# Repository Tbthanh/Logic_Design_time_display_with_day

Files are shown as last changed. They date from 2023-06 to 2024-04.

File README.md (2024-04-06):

# Logic_Design_time_display_with_day<br>

**Team's member:**<br>
Đinh Quoc An<br>
Bui Manh Huy<br>
Nguyen The (Saxo Cat) Minh Quan<br>
Tran Ba Thanh<br>
Nguyen Minh Tuan<br>

**Project objective:**<br>
This project aim is to deepen our knowledge about logic design, ic 74xx series, CAD-SPICE sofware (proteus, altium),...

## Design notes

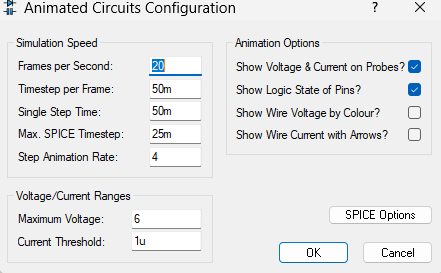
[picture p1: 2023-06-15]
Multimedia/Default_option_for_animation_Proteus.png

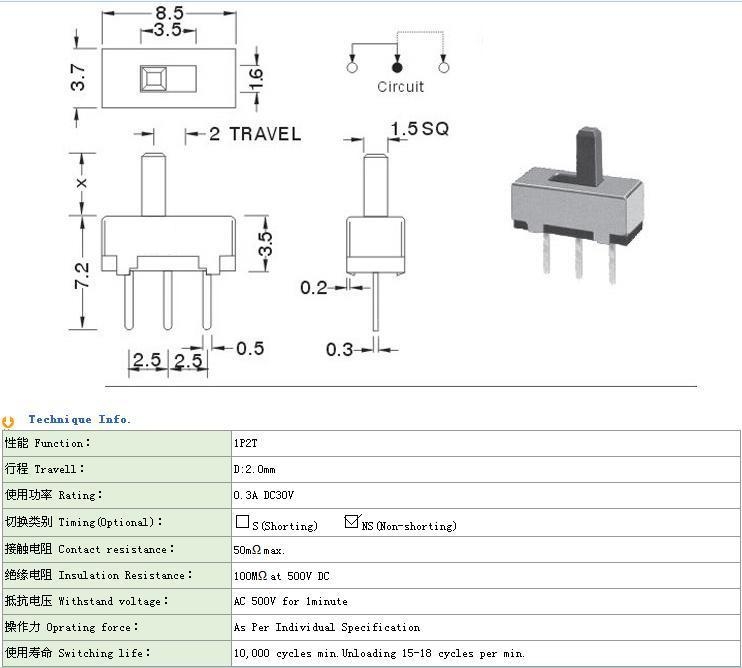
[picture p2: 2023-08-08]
Document/Switch/SS-12D002.jpg

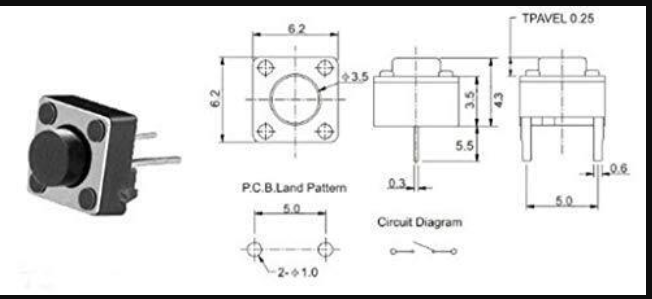
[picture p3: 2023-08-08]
Document/Switch/2_pin_switch_6x6x5MM.png

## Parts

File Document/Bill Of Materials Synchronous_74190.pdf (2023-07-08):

## Bill Of Materials for Synchronous_74190

Design Title | Synchronous_74190

### Author Document Number Revision

Design Created | Monday, July 3, 2023

### Design Last Modified Saturday, July 8, 2023 Total Parts In Design 62

0 Modules
Quantity | References | Value | Stock Code | Unit Cost
Sub-totals: | | | | $0.00
8 Capacitors
Quantity | References | Value | Stock Code | Unit Cost
1 | C1 | 10nF
1 | C2 | 10uF
6 | C3-C8 | 1nF
Sub-totals: | | | | $0.00
8 Resistors
Quantity | References | Value | Stock Code | Unit Cost
1 | R1 | 67k
1 | R2 | 10k
6 | R3-R8 | 220
Sub-totals: | | | | $0.00
44 Integrated Circuits
Quantity | References | Value | Stock Code | Unit Cost
1 | U1 | NE555
12 | U2-U3,U6-U7,U10-U11,U16-U19,U21-U22 | 74LS47
12 | U4,U8-U9,U12-U15,U20,U23-U25,U33 | 74190
3 | U5,U27,U41 | 74LS08
1 | U26 | 7473
3 | U28,U30,U43 | 74LS21
3 | U29,U34,U50 | 74LS11
3 | U31,U35,U44 | 7404
1 | U32 | 74LS86
2 | U38,U52 | 7432
2 | U39,U42 | 74157
1 | U49 | 74LS00
Sub-totals: | | | | $0.00
0 Transistors
Quantity | References | Value | Stock Code | Unit Cost
Sub-totals: | | | | $0.00
1 Diodes
Quantity | References | Value | Stock Code | Unit Cost
1 | D1 | DIODE
Sub-totals: | | | | $0.00
1 Miscellaneous
Quantity | References | Value | Stock Code | Unit Cost
1 | SW1 | SW-SPDT
Sub-totals: | | | | $0.00
Totals: | | | | $0.00

Saturday, July 8, 2023 6:01:08 PM

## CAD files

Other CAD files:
Multimedia/graphics_files/time_display_with_day_PCB_des.DXF
Document/graphics_files/OLD_time_display_with_day_PCB_des_old_version (1).DXF

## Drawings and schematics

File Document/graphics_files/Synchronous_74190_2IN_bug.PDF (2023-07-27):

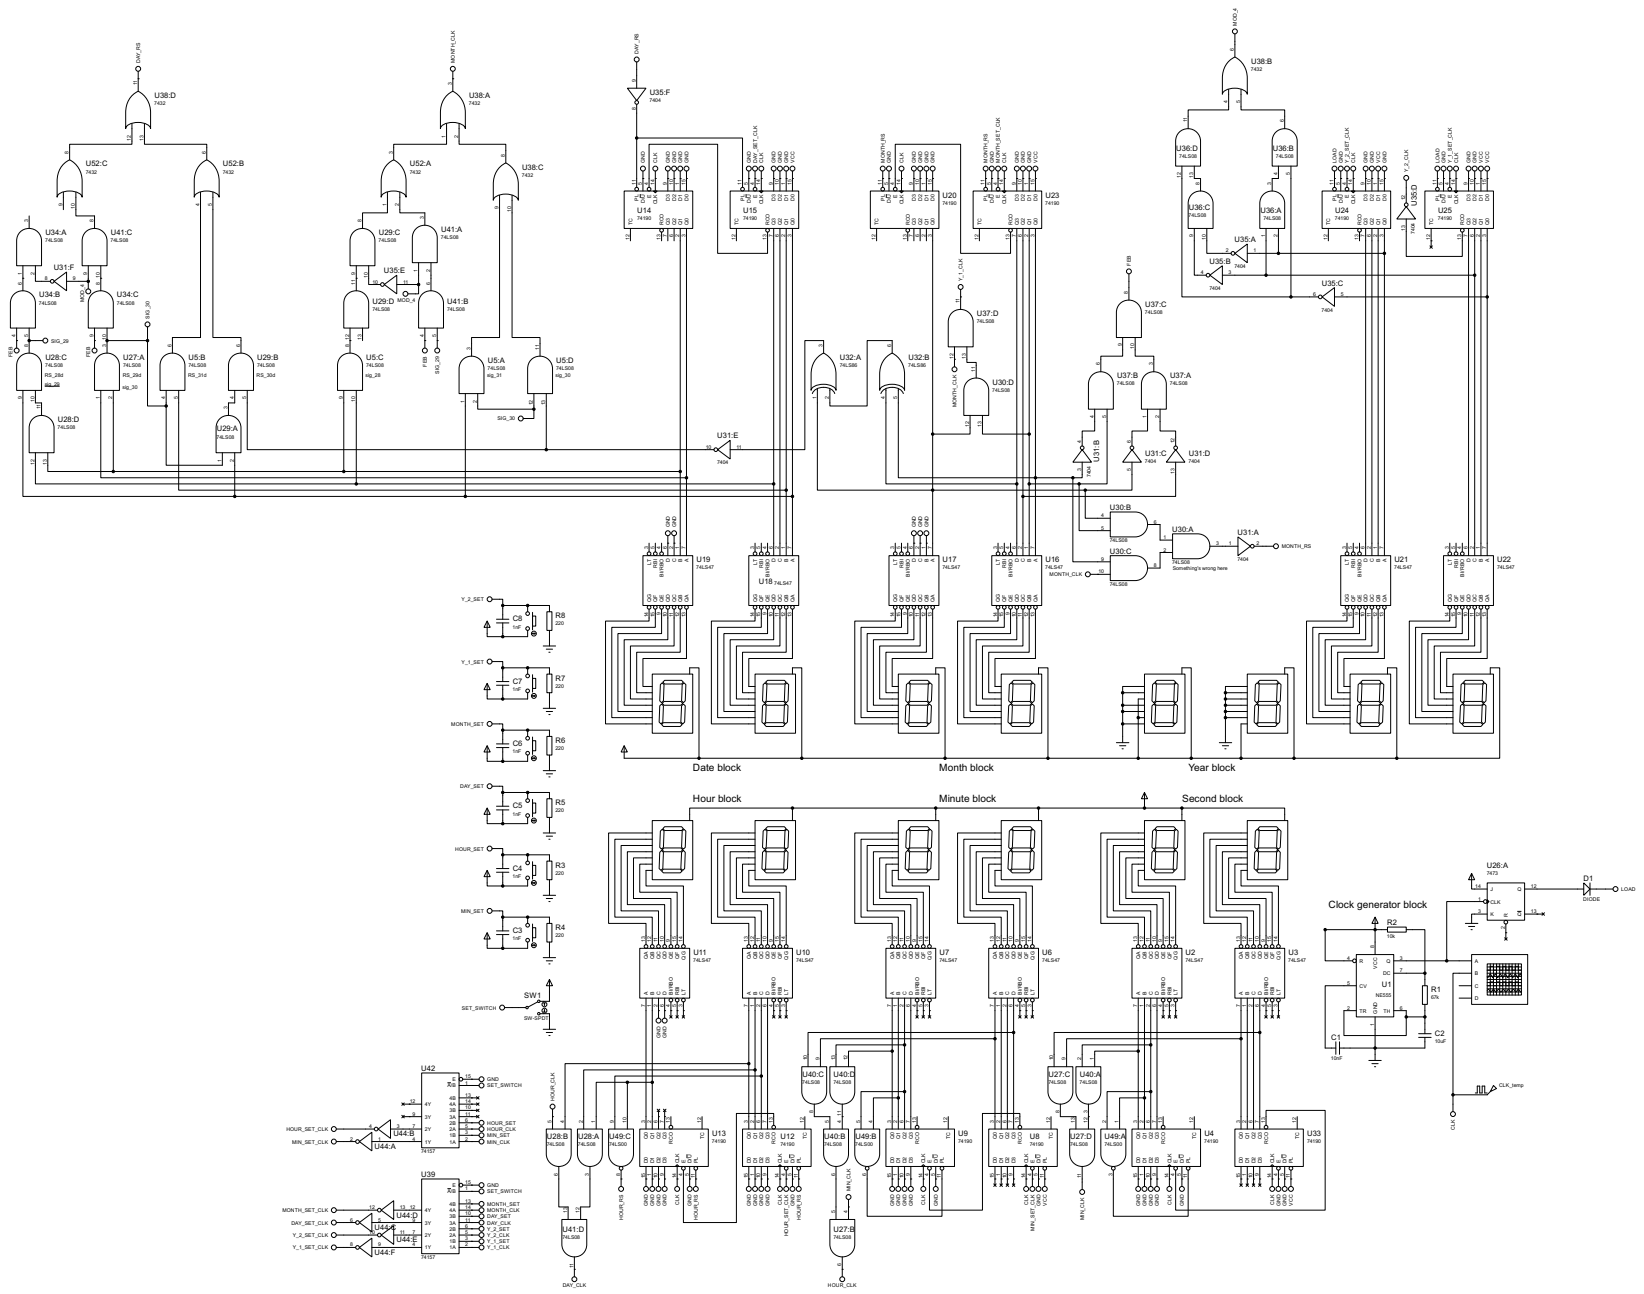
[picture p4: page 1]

GND GND

VCC GND GND GND

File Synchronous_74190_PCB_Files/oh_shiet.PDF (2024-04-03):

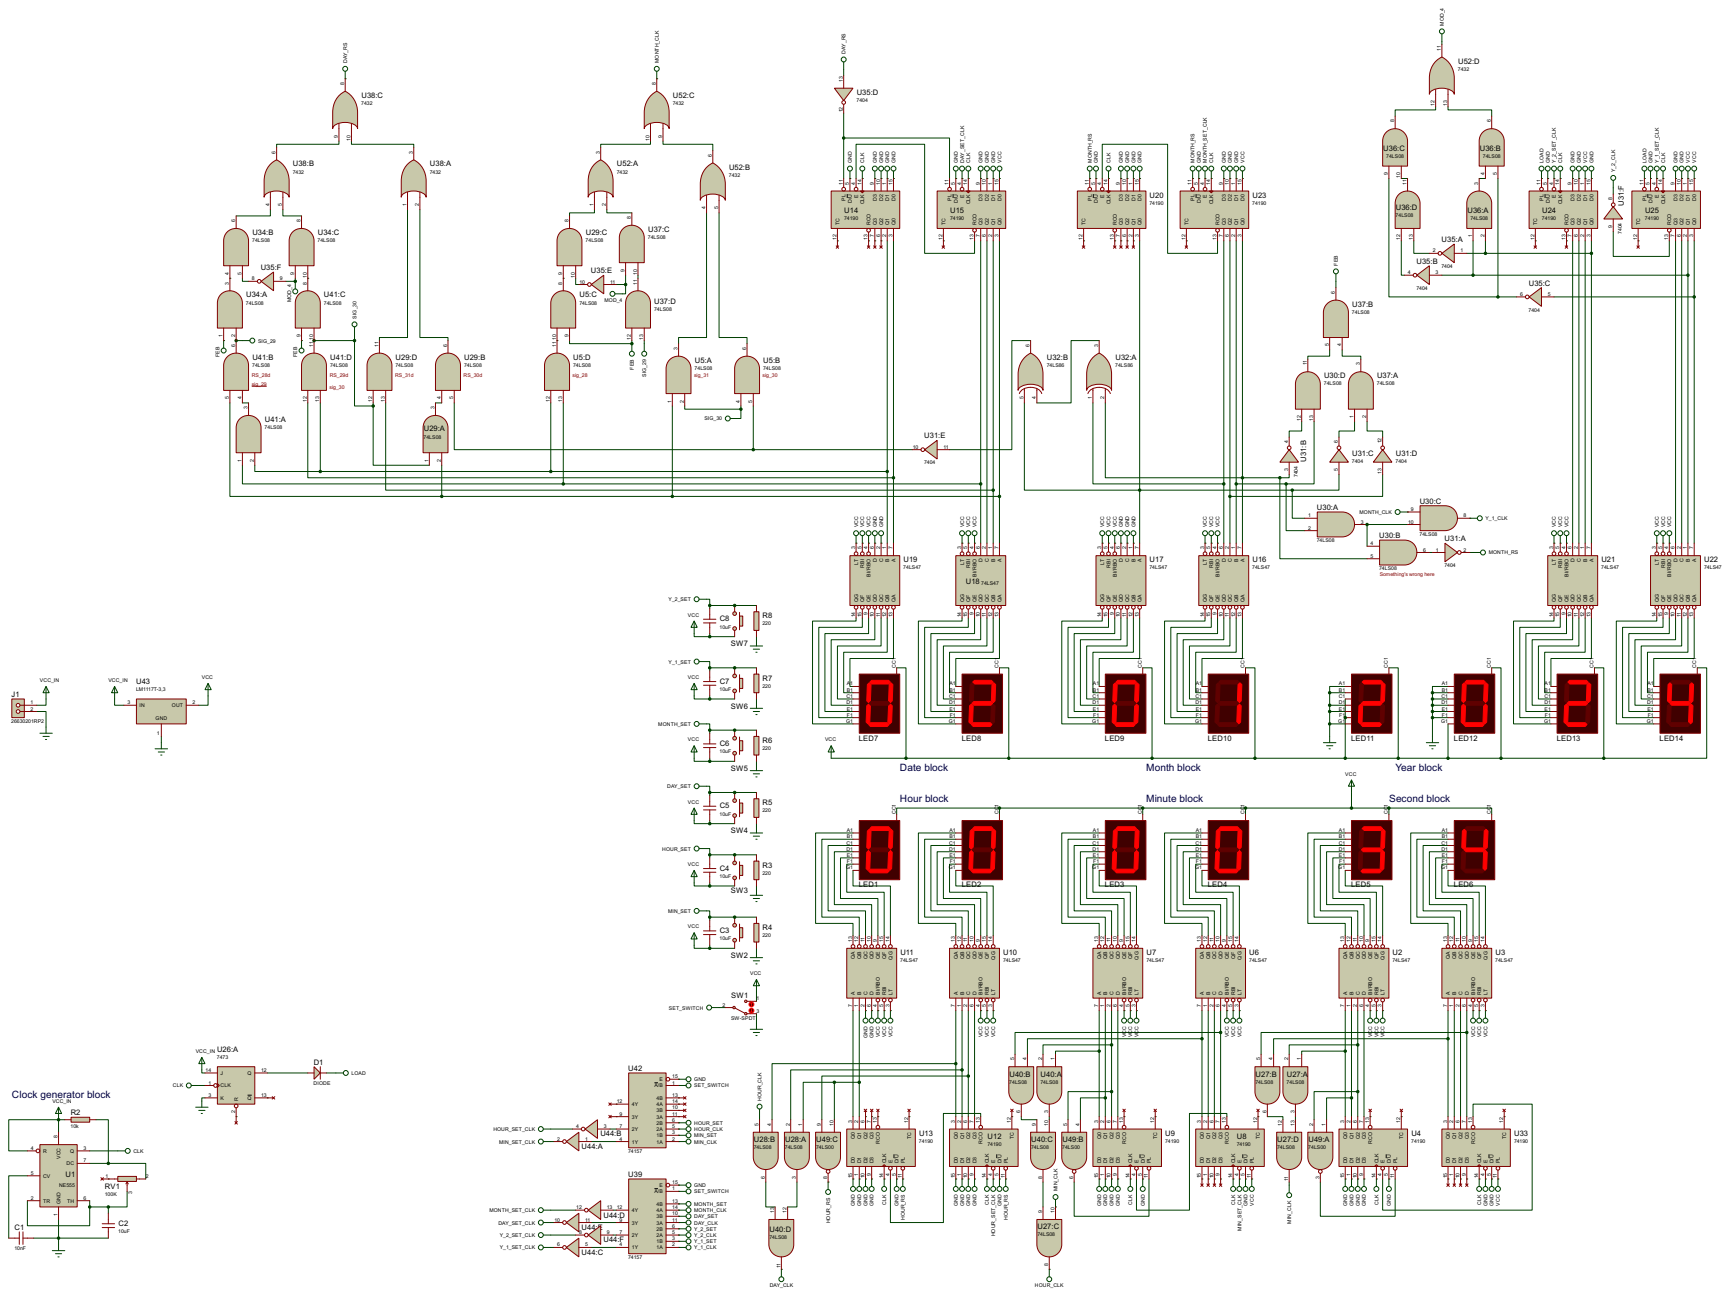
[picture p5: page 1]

GND GND

VCC GND GND GND

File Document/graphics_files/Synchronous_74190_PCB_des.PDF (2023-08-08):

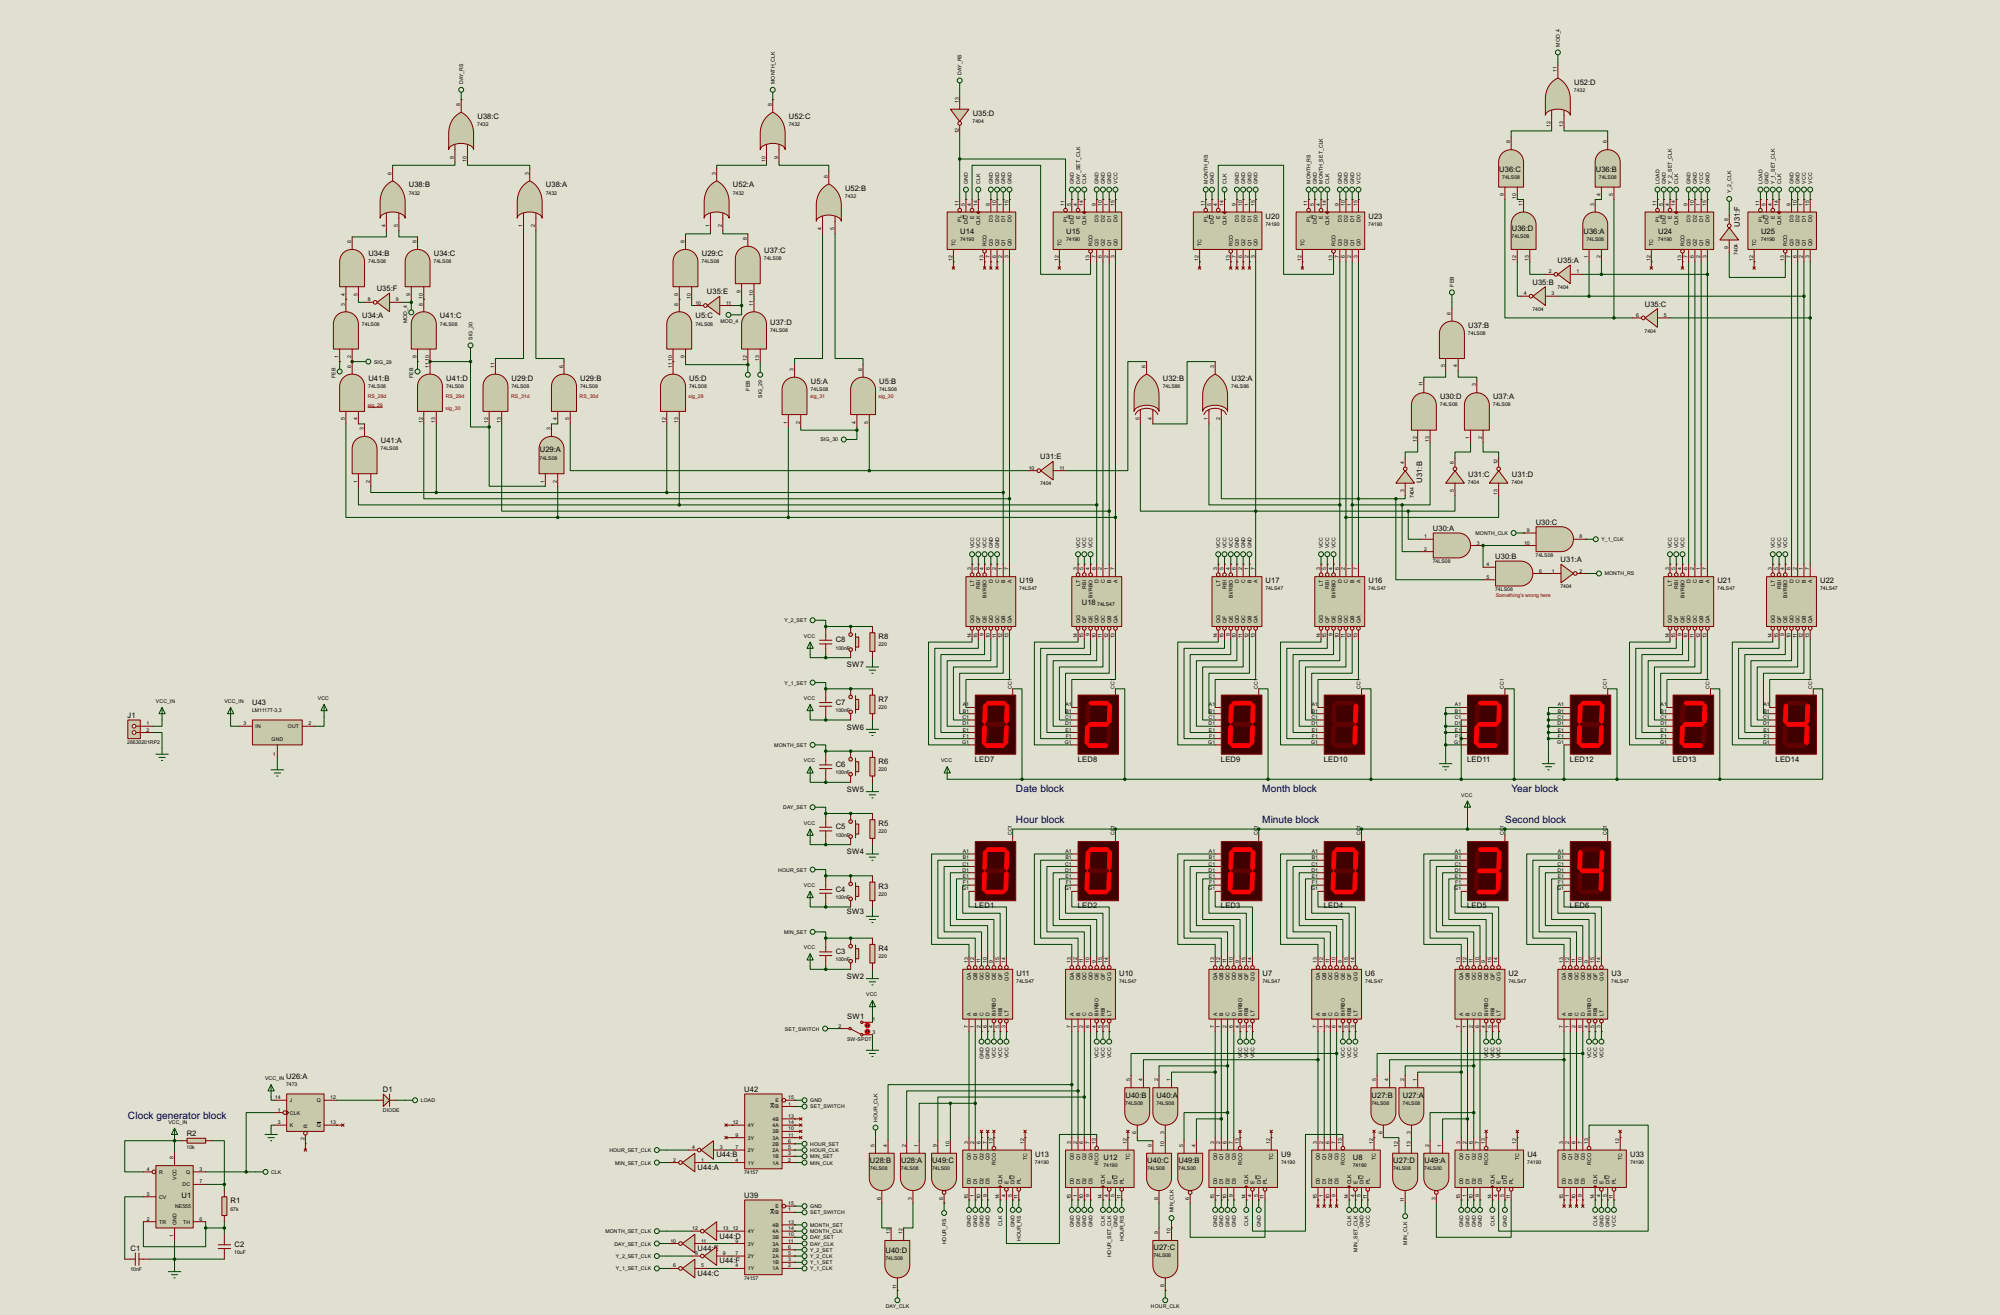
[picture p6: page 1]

GND GND

VCC GND GND GND

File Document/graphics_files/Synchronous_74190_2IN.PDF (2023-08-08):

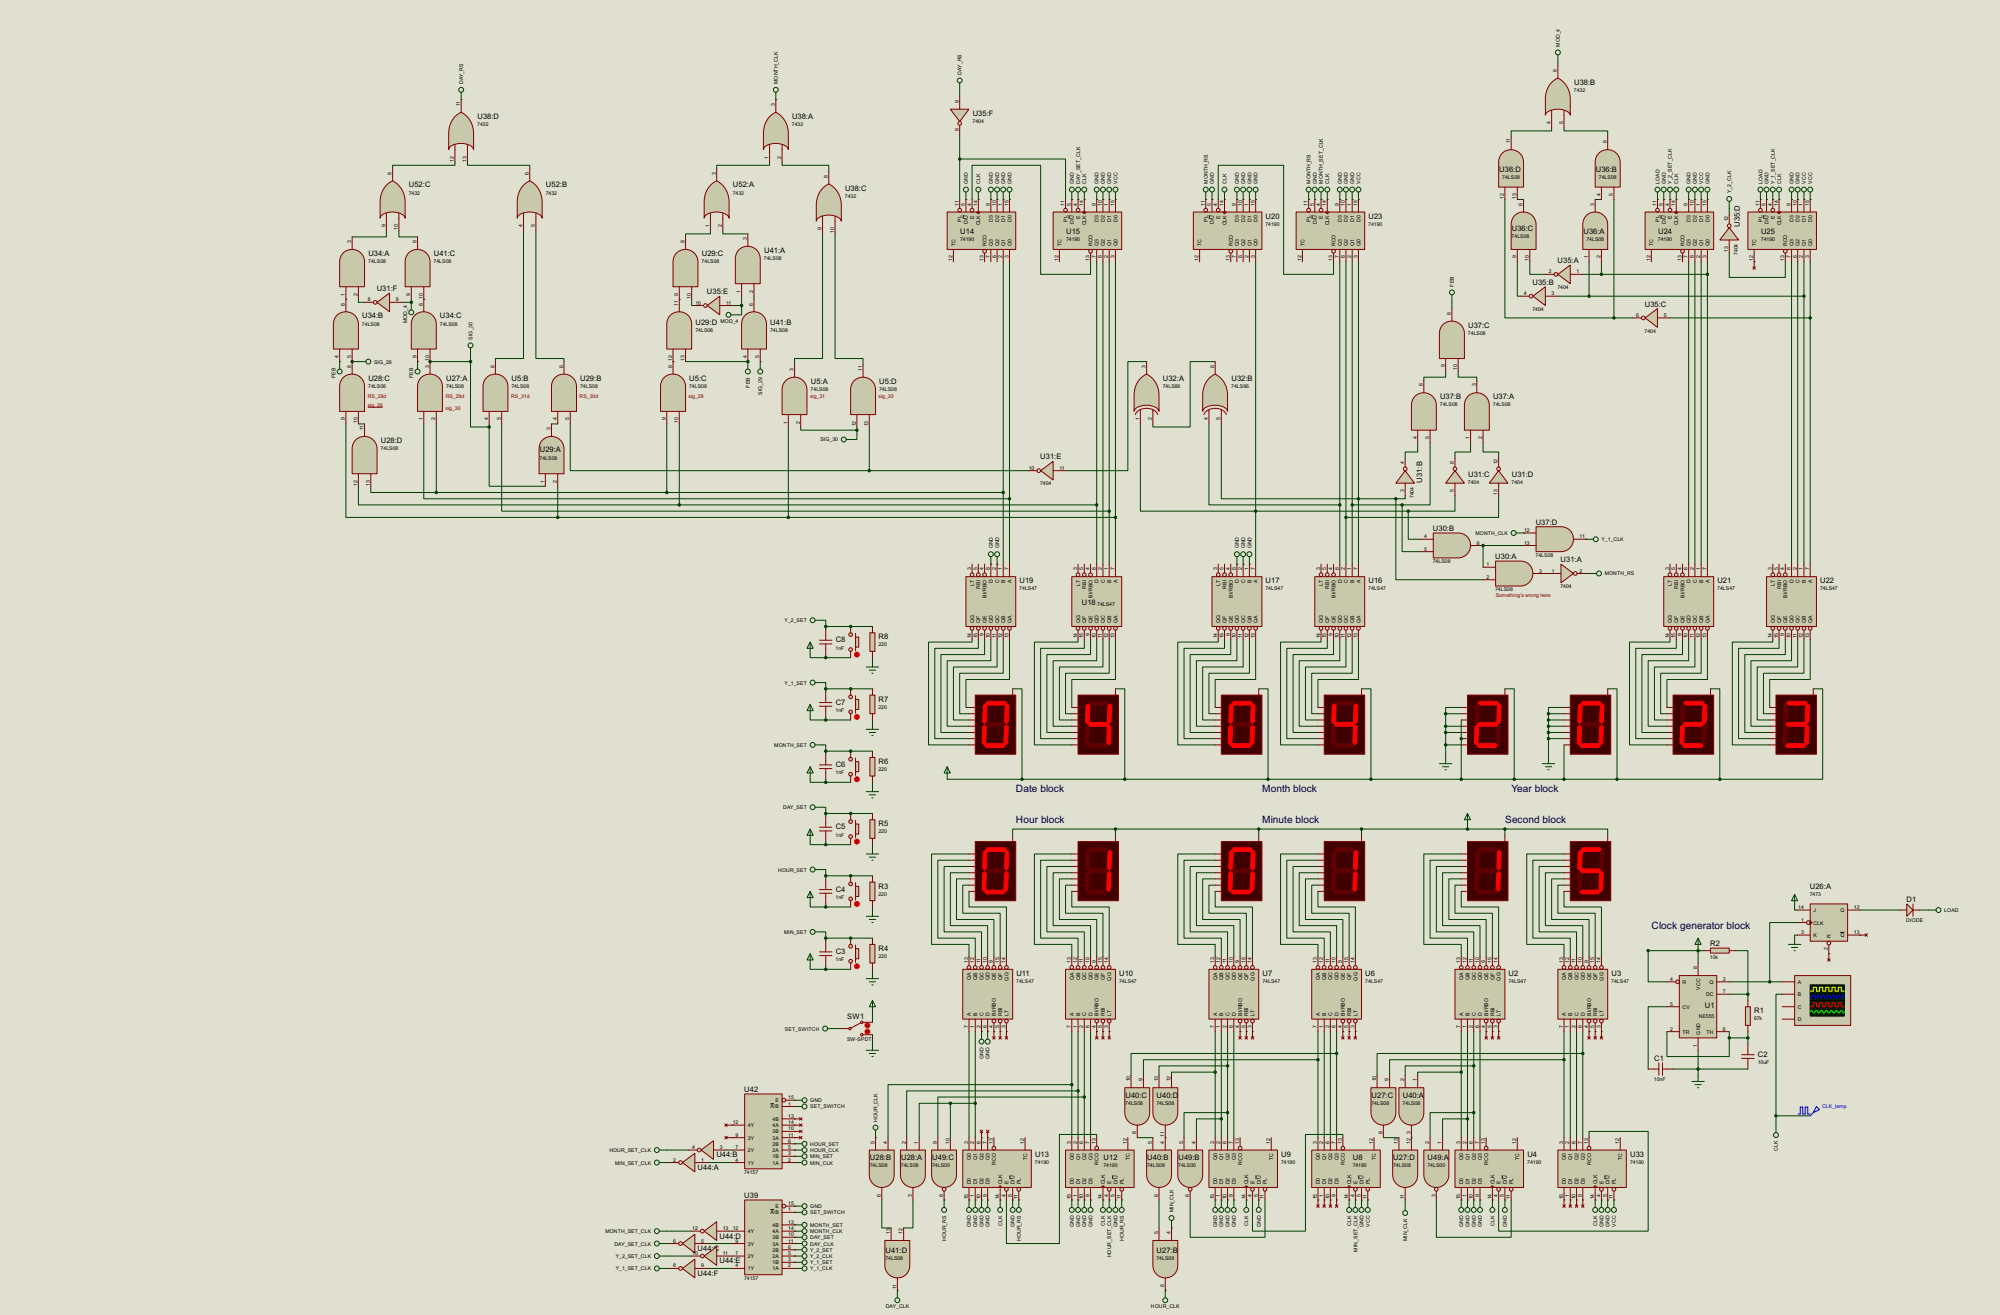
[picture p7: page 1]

GND GND

VCC GND GND GND

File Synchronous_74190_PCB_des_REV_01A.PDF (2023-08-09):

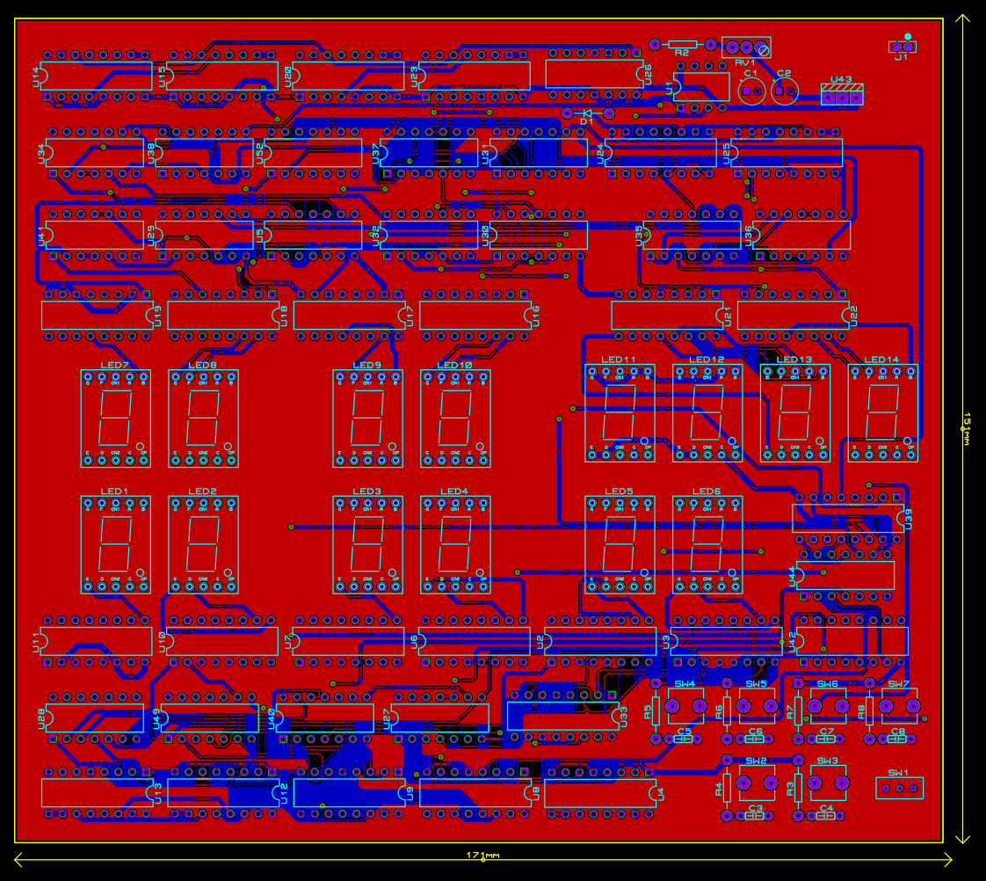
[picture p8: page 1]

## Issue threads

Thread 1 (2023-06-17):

The Leap Year Problem

buihuy1203, 2023-06-17:
With 2100, it's not leap year But, it's still count as leap year. So I have some adjust to the schematic file. Hope you make it clearly

Tbthanh, 2023-06-17:
fixed

Closed 2023-06-17.

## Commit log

2023-06-15 Added mux, wired set and clk for minutes
2023-06-16 Prepare to replace the BUTTON
    I'll replace the BUTTON to the PUSH-BUTTON (YZDEVLIB - SW-PUSH-2T). After this push, I will replace it in the file with BUTTON in its name.
2023-06-16 Start pcb design
2023-06-17 1st led change
2023-06-17 PCB design officially started
2023-06-17 Give up and go to sleep, but PCB finally ready
2023-06-17 Create some pdf, dwg, svg of schematic
    [time_display_with_day_PCB_des.DXF]
2023-06-18 Officially ready to design PCB
    Added 2 pin connector to get power. Added 2 x 10ohm resistor to LED to ensure that they don't fry when use
2023-06-18 Export graphics
    Just to view schematic on other monitor, device for faster PCB design.
    [time_display_with_day_PCB_des_old_version.DXF]
2023-06-18 Officially ready to design PCB
    Added SaxoCatto to the co-authors
2023-06-22 Switch from asynchronous to synchronous counter
    The asynchronous counter is not great, too many error and so on so on so our professor make us do the synchronous ones
2023-06-23 Synchronous file: Bug with CLK from 555
    The CLK signal from ic 555 provide to ic 74192 but the 192 doesnt count. But when switch to the CLK from proteus, the 192 work normally.
2023-06-23 BUG in minutes set button
2023-06-28 Date, Month, Hour, Min working
    Just some more tweak to the leap year logic and then we will moved on to PCB
2023-07-03 IC NOT CLK TOGETHER
    All the counter IC need to be feed with the CLK from ne555 (aka. 1hz CLK). So scrap all the 74192 and moved on to 74190 or 74160
2023-07-03 190 clear issue
    I forgot that 74ls190 don't have a clear pin so just have to maneuver with the enable pin for now
    [time_display_with_day_PCB_des_old_version.DXF]
2023-07-03 Tired of NAND bug
    My theory here is because the signal 60 going through the NAND is offset or late compare to the CLK make the signal to the next block error.
2023-07-06 Red led, year preset & day
2023-07-07 Redesign the logic for date block
    Changing from Enable+CLK combo to separate Enable and CLK pin cause some issue, and I don't feel good with my old design so ...
2023-07-08 Still some issue with chaining ics
2023-07-13 added breadbroad
    But nothing there yet
    [Breadbroad_pinout.fzz]
2023-07-27 upload PDF
    chia linh kiện boiz
2023-08-04 Havent fix the pin yet.
2023-08-04 Minus 1 logic gate at Month block
    [Breadbroad_pinout.fzz]
2023-08-04 fritzing file for month (unfinish)
    [Breadbroad_pinout.fzz]
2023-08-08 PCB design start again :wink:
2023-08-08 PCB design 10% there
2023-08-08 30% PCB _ 3am
    Go to sleep
    [OLD_time_display_with_day_PCB_des_old_version (1).DXF]
2023-08-09 Waiting for the PCB
